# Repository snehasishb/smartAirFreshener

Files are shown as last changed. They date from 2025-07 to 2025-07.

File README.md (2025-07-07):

# smartAirFreshener
1. The air freshener unit is operated by 2 X AA batteries, resulting in a nominal supply voltage of 3V DC. This derives the air fresheners is designed to operate within this 3V DC range. In alignment with this standard, the output pin intended for interfacing with the air freshener has been configured to deliver a regulated 3V DC. You should determine the required operating voltage for your specific air freshener based on the same factors.
2. Make sure you have Home Assistant (https://www.home-assistant.io/) server running in your local to implement this project.
3. After completing the initial version of the project, I observed that a 2500mAh battery lasted approximately one day under continuous operation with the original code. Upon reviewing the codebase, I identified opportunities to optimize power consumption. To improve power efficiency, I implemented several optimizations. This included enabling the deep sleep function, restricting Wi-Fi connectivity to wake-up intervals only, and removing the MQTT-based on/off control previously integrated with Home Assistant, which was causing unnecessary background activity. As a result of these enhancements, the battery life of the device increased significantly—from approximately one day to nearly two weeks using a 2500mAh battery.
4. Electronics Components:
#ESP-WROOM-32 (ESP32 Dev Board)
#1 Channel Relay Module 5V High and Low Level Trigger Relay Module
#Mini DC-DC Boost Converter 0.9V~5V to 5V 600MA USB Output charger step up Power Module
#Type-C USB 5V 2A Step-Up Boost Converter with USB Charger
#18650 SMD/SMT High-Quality Single Battery Holder
#DMEGC INR18650-26E 3.7V 2600mAh Li-Ion Battery
#2 X diode 1N4007
#2.1×5.5mm DC Power Jack Socket Panel Mount (Female) 
#Slide Switch SS-12D00 1P2T

AirFreshner Diagram

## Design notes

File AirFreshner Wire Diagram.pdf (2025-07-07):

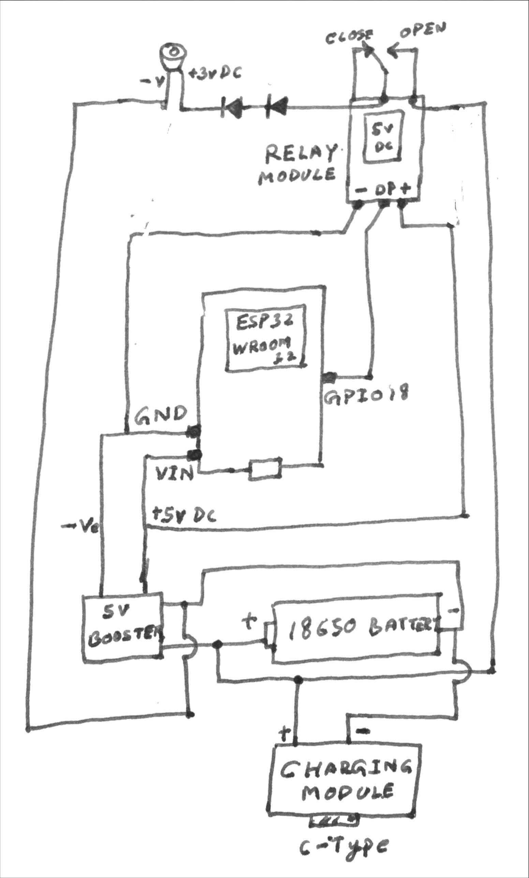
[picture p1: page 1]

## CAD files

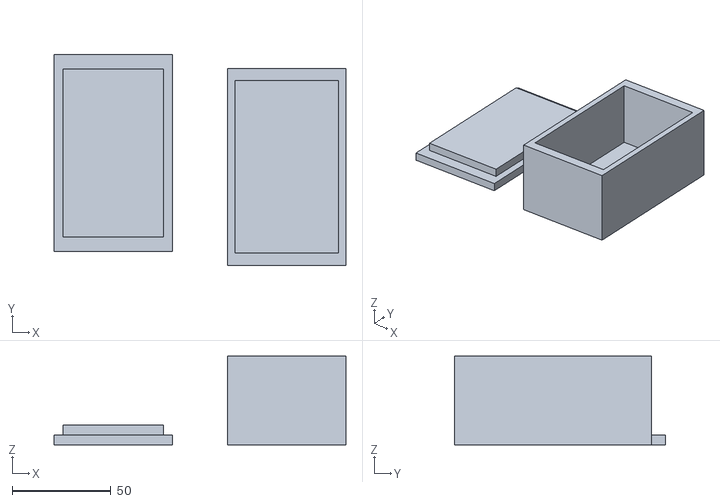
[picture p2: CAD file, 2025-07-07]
smartAirFreshener.stl
148.0 x 107.0 x 45.0

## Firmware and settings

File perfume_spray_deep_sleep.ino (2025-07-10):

#include <WiFi.h>
#include <PubSubClient.h>
#include <Preferences.h>
#include <esp_sleep.h>

#define RELAY_PIN 18

// Wi-Fi Credentials
const char* ssid = "SSID";
const char* password = "password";

// MQTT
const char* mqtt_server = "192.168.1.25";
const int mqtt_port = 1883;
const char* mqtt_user = "mqttuser";
const char* mqtt_pass = "hydrogen";
const char* mqtt_client_id = "ESP32PerfumeClient";

const char* topic_status = "home/perfumespray/status";
const char* topic_spray_count = "home/perfumespray/count";

// Time management
#define MAX_WIFI_RETRY_TIME 90000        // 1.5 minutes
#define MAX_MQTT_RETRY_TIME 90000        // 1.5 minutes
#define TOTAL_TIMEOUT_MS    180000       // Total 3 minutes max
#define SPRAY_INTERVAL_SEC  3600         // 1 hour deep sleep

WiFiClient espClient;
PubSubClient client(espClient);
Preferences prefs;

int sprayCount = 0;

// Trigger relay to spray
void triggerRelay() {
  Serial.println("Spraying perfume...");
  digitalWrite(RELAY_PIN, HIGH);
  delay(3000); // Spray duration
  digitalWrite(RELAY_PIN, LOW);
}

// Try Wi-Fi with timeout
bool connectWiFiWithTimeout() {
  Serial.println("Connecting to WiFi...");
  WiFi.begin(ssid, password);

  unsigned long start = millis();
  while (WiFi.status() != WL_CONNECTED && millis() - start < MAX_WIFI_RETRY_TIME) {
    delay(500);
    Serial.print(".");
  }

  if (WiFi.status() == WL_CONNECTED) {
    Serial.println("\nWiFi connected!");
    return true;
  } else {
    Serial.println("\nWiFi connection FAILED");
    return false;
  }
}

// Try MQTT with timeout
bool connectMQTTWithTimeout() {
  client.setServer(mqtt_server, mqtt_port);
  unsigned long start = millis();

  while (!client.connected() && millis() - start < MAX_MQTT_RETRY_TIME) {
    Serial.print("Attempting MQTT...");
    if (client.connect(mqtt_client_id, mqtt_user, mqtt_pass)) {
      Serial.println("connected");
      return true;
    } else {
      Serial.print("failed, rc=");
      Serial.println(client.state());
      delay(1000);
    }
  }

  Serial.println("MQTT connection FAILED");
  return false;
}

// Publish spray status and count
void publishMQTT() {
  char countStr[10];
  itoa(sprayCount, countStr, 10);

  client.publish(topic_status, "ON");
  client.publish(topic_spray_count, countStr);
  delay(500);
  client.publish(topic_status, "OFF");
}

void setup() {
  Serial.begin(115200);
  pinMode(RELAY_PIN, OUTPUT);
  digitalWrite(RELAY_PIN, LOW);

  unsigned long startMillis = millis();

  // Restore spray count from flash
  prefs.begin("spray", false);
  sprayCount = prefs.getInt("sprayCount", 0);

  // Connect Wi-Fi
  bool wifiOK = connectWiFiWithTimeout();
  bool mqttOK = false;

  if (wifiOK) {
    mqttOK = connectMQTTWithTimeout();
  }

  // Spray anyway, whether or not MQTT works
  sprayCount++;
  prefs.putInt("sprayCount", sprayCount);
  triggerRelay();

  // If MQTT is okay, publish count
  if (mqttOK && client.connected()) {
    publishMQTT();
  }

  // Respect total timeout of 3 minutes
  unsigned long totalElapsed = millis() - startMillis;
  if (totalElapsed < TOTAL_TIMEOUT_MS) {
    delay(TOTAL_TIMEOUT_MS - totalElapsed);
  }

  Serial.println("Going to deep sleep for 1 hour...");
  esp_sleep_enable_timer_wakeup(SPRAY_INTERVAL_SEC * 1000000ULL);
  esp_deep_sleep_start();
}

void loop() {
  // unused – execution never returns from deep sleep
}

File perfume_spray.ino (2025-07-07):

#include <WiFi.h>
#include <PubSubClient.h>
#include <Preferences.h>
#include <ArduinoOTA.h>

#define RELAY_PIN 18  // GPIO18 controls relay (ACTIVE HIGH)

// WiFi credentials
const char* ssid = "YOUR SSID";
const char* password = "YOUR PASSWORD";

// MQTT Broker (IP address of Home Assistant)
const char* mqtt_server = "192.168.1.25";
const int mqtt_port = 1883;
const char* mqtt_user = "mqttuser";
const char* mqtt_pass = "password";
const char* mqtt_client_id = "ESP32PerfumeClient";

// MQTT Topics
const char* topic_control = "home/perfumespray/control";
const char* topic_status = "home/perfumespray/status";
const char* topic_spray_count = "home/perfumespray/count";

// Timing
unsigned long lastTrigger = 0;
const unsigned long sprayInterval = 3600000UL;  // 1 hour

// Spray count (stored in non-volatile memory)
Preferences prefs;
int sprayCount = 0;

WiFiClient espClient;
PubSubClient client(espClient);

void triggerRelay() {
  Serial.println("Spraying perfume...");
  digitalWrite(RELAY_PIN, HIGH);   // Relay ON
  client.publish(topic_status, "ON");
  delay(3000);
  digitalWrite(RELAY_PIN, LOW);    // Relay OFF
  client.publish(topic_status, "OFF");

  // Update spray count
  sprayCount++;
  prefs.putInt("sprayCount", sprayCount);

  // Publish updated count
  char countStr[10];
  itoa(sprayCount, countStr, 10);
  client.publish(topic_spray_count, countStr);
}

void mqttCallback(char* topic, byte* payload, unsigned int length) {
  String msg = "";
  for (unsigned int i = 0; i < length; i++) {
    msg += (char)payload[i];
  }
  Serial.printf("MQTT message received [%s]: %s\n", topic, msg.c_str());

  if (String(topic) == topic_control && msg == "ON") {
    triggerRelay();
  }
}

void reconnectMQTT() {
  while (!client.connected()) {
    Serial.print("Connecting to MQTT...");
    if (client.connect(mqtt_client_id, mqtt_user, mqtt_pass)) {
      Serial.println("connected");
      client.subscribe(topic_control);
    } else {
      Serial.print("failed, rc=");
      Serial.println(client.state());
      delay(2000);
    }
  }
}

void setupOTA() {
  ArduinoOTA.setHostname("perfumespray");
  ArduinoOTA.begin();
}

void setup() {
  Serial.begin(115200);

  pinMode(RELAY_PIN, OUTPUT);
  digitalWrite(RELAY_PIN, LOW);  // OFF by default (active HIGH relay)

  WiFi.setHostname("perfumespray");
  WiFi.begin(ssid, password);
  Serial.print("Connecting to WiFi");
  while (WiFi.status() != WL_CONNECTED) {
    delay(500);
    Serial.print(".");
  }
  Serial.println("\nWiFi connected. IP: " + WiFi.localIP().toString());

  setupOTA();

  client.setServer(mqtt_server, mqtt_port);
  client.setCallback(mqttCallback);

  prefs.begin("spray", false);
  sprayCount = prefs.getInt("sprayCount", 0);
  Serial.printf("Spray count (restored): %d\n", sprayCount);
}

void loop() {
  ArduinoOTA.handle();

  if (!client.connected()) {
    reconnectMQTT();
  }
  client.loop();

  unsigned long currentMillis = millis();
  if (currentMillis - lastTrigger >= sprayInterval) {
    triggerRelay();
    lastTrigger = currentMillis;
  }
}

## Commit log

2025-07-07 3d model box
    [smartAirFreshener.stl]
2025-07-07 print without any editing
2025-07-10 battery power saving code
